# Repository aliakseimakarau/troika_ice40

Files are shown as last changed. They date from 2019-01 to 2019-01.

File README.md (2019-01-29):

This is an implementation of the Troika hashing algorithmus on ICE40 FPGAs.

The repository is intended to be used by developers who are considering using Troika in their hardware projects. The board-files are from a PoC which can be used as design example.

It's not a high-performance solution because it needs multiple clock-cycles per hash-round and the implementation is heavily restricted by logic resources and achievable speed of ICE40 FPGAs. But the FPGA is very cheap, the PCB can be done by any cheap chinese manufacturer and soldering is doable with a bit of practice. And it's a lot faster than doing hash calculations only in software if using e.g. auto-padding and/or multi-hash-loops. IOTA library functions can benefit much because 1. it works much with 243Trit vectors and 2. they often do multiple hashing loops (e.g. address generation, signing).

Support for this repository is limited because it's just a PoC and intended for experienced developers. (by the way, it's the same PCB as for the PoWChip PoC - for Troika the GSM/BT/GPS modul is not needed and software for it is not included in the repository).

Some features (FPGA):
- ICE40UP5K ($5 FPGA in QFN package)
- FPGA about 73% utilized
- running at 36MHz (uses internal 48MHz oscillator + PLL; no external oscillator required)
- Data-transfers via SPI
- It needs 55 clock cycles per hash
- It can do auto-padding for 243Trit input size (single Block; in IOTA used a lot)
- It can do multiple loops with auto-padding (this is interesting for e.g. IOTA where often a block has to be hashed multiple times; It reduces transfer-times significantly)
- It supports nested hashing by "push"ing" and "pop"ing the internal Troika state to and from a "Stack" (actually, it's an internal offset for RAM address but it acts like a stack).

PCB:
- ICE40UP5K FPGA
- STM32F302CCTx µC (default DFU Bootloader can be used)
- Pinheader for GSM/GPS/BT module (not used in this application)
- Some LEDs, Buttons
- SWD Debug header

Performance:
- 10k blocks (including SPI transfer times) in 11.6s
- 1k blocks with 27 hash-loops (including SPI transfer times and auto-padding) in 2.6s

This repository contains:
- Radiant project files for ICE40 FPGAs with VHDL source files
- Example Board-Design
- Eclipse project with code for STM32F302

Just a small note ... A synthesized ICE40 Bitstream is included in the STM32-code (bitstream.h)

License (MIT):
```
-- 2018 by Thomas Pototschnig <microengineer18@gmail.com,
-- http://microengineer.eu
-- discord: pmaxuw#8292
-- donations-address: 
--     LLEYMHRKXWSPMGCMZFPKKTHSEMYJTNAZXSAYZGQUEXLXEEWPXUNWBFDWESOJVLHQHXOPQEYXGIRBYTLRWHMJAOSHUY
-- 
-- Permission is hereby granted, free of charge, to any person obtaining
-- a copy of this software and associated documentation files (the
-- "Software"), to deal in the Software without restriction, including
-- without limitation the rights to use, copy, modify, merge, publish,
-- distribute, sublicense, and/or sell copies of the Software, and to
-- permit persons to whom the Software is furnished to do so, subject to
-- the following conditions:
-- 
-- The above copyright notice and this permission notice shall be
-- included in all copies or substantial portions of the Software.
-- 
-- THE SOFTWARE IS PROVIDED "AS IS", WITHOUT WARRANTY OF ANY KIND,
-- EXPRESS OR IMPLIED, INCLUDING BUT NOT LIMITED TO THE WARRANTIES OF
-- MERCHANTABILITY, FITNESS FOR A PARTICULAR PURPOSE AND
-- NONINFRINGEMENT. IN NO EVENT SHALL THE AUTHORS OR COPYRIGHT HOLDERS BE
-- LIABLE FOR ANY CLAIM, DAMAGES OR OTHER LIABILITY, WHETHER IN AN ACTION
-- OF CONTRACT, TORT OR OTHERWISE, ARISING FROM, OUT OF OR IN CONNECTION
-- WITH THE SOFTWARE OR THE USE OR OTHER DEALINGS IN THE SOFTWAR
```

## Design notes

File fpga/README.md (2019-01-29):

This is an implementation of the Troika hashing algorithmus on ICE40 FPGAs.

The repository is intended to be used by developers who are considering using Troika in their hardware projects. The board-files are from a PoC which can be used as design example.

It's not a high-performance solution because it needs multiple clock-cycles per hash-round and the implementation is heavily restricted by the architecture (and logic resources) of ICE40 FPGAs. But the FPGA is very cheap, the PCB can be done by any cheap chinese manufacturer and soldering is doable with a bit of practice. And it's a lot faster than doing hash calculations only in software if using e.g. auto-padding and/or multi-hash-loops. IOTA library functions can benefit much because 1. the work much with 243Trit vectors and 2. they often do multiple hashing loops (e.g. address generation, signing).

Some features:
- ICE40UP5K ($5 FPGA in QFN package)
- FPGA about 73% utilized
- running at 36MHz (uses internal 48MHz oscillator + PLL; no external oscillator required)
- Data-transfers via SPI
- It needs 55 clock cycles per hash
- It can do auto-padding for 243Trit input size (single Block; in IOTA used a lot)
- It can do multiple loops with auto-padding (this is interesting for e.g. IOTA where often a block has to be hashed multiple times; It reduces transfer-times significantly)
- It supports nested hashing by "push"ing" and "pop"ing the internal Troika state to and from a "Stack" (actually, it's an internal offset for RAM address but it acts like a stack).

Performance:
- 10k blocks (including SPI transfer times) in 11.6s
- 1k blocks with 27 hash-loops (including SPI transfer times and auto-padding) in 2.6s

This repository contains:
- Radiant project files for ICE40 FPGAs with VHDL source files
- Example Board-Design
- Eclipse project with code for STM32F302

Just a small note ... A synthesized ICE40 Bitstream is included in the STM32-code (bitstream.h)

If you like my work please consider donating:
LLEYMHRKXWSPMGCMZFPKKTHSEMYJTNAZXSAYZGQUEXLXEEWPXUNWBFDWESOJVLHQHXOPQEYXGIRBYTLRWHMJAOSHUY

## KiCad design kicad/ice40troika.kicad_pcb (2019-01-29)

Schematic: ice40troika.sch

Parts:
C1, C2, C10, C11, C32, C34, C35: 1µ; C_0603_1608Metric
C3, C36: 10µ; C_0603_1608Metric
C4, C5, C6, C7, C12, C13, C16, C19, C20, C24, C25, C26, C27, C31, C33: 100n; C_0603_1608Metric
C8, C9, C14, C15, C18: 10n; C_0603_1608Metric
C17, C28, C29, C30: 47µ; C_1210_3225Metric
C21: 4.7µ/X5R; C_1206_3216Metric
C22, C23: 47p; C_0603_1608Metric
D1: D; D_SOD-523
D2, D3: LED; LED_0603_1608Metric
JP1: Jumper_NC_Dual; SolderJumper-3_P1.3mm_Open_RoundedPad1.0x1.5mm
P1: 10104110-0001LF; MICROUSBB
P2: CONN_01X05; PinHeader_1x05_P1.27mm_Vertical
R1, R2, R4, R6, R7, R9, R12, R18, R19, R22: 10k; R_0603_1608Metric
R3: 100; R_0603_1608Metric
R5: 100k; R_0603_1608Metric
R8, R11, R13, R20: 22; R_0603_1608Metric
R10: 1k5; R_0603_1608Metric
R14, R21: 270; R_0603_1608Metric
R15: 1; R_1210_3225Metric
R16, R17: 33; R_0603_1608Metric
SW1, SW2, SW3: KMR2; SW_SPST_KMR2
U1: ice40up5k; ice40up-QFN-48
U3: USBLC6-2SC6; SOT-23-6
U4: STM32F302CCT6; LQFP-48_7x7mm_P0.5mm
U5: SIM808
U6: LP2985-3.3; SOT-23-5
U7: MIC5504-1.2YM5; SOT-23-5
X1: 8MHz; Oscillator_SMD_Abracon_ASE-4Pin_3.2x2.5mm

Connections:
+1V2: C2.1, C6.1, C9.1, C31.1, R3.2, R15.1, U1.5, U1.30
+3V3: C1.1, C4.2, C5.1, C8.1, C10.1, C11.1, C12.1, C13.1, C14.1, C15.1, C16.1, C24.1, C25.1, C26.1, C27.1, C34.1, C36.1, D1.2, R1.2, R2.2, R4.2, R6.2, R9.1, R10.2, R14.1, R21.1, SW2.1, SW3.1, U1.1, U1.22, U1.33, U4.9, U4.24, U4.36, U4.48, U6.5 (VOUT), U7.1 (VIN), U7.3 (EN), X1.4
/CDONE: R4.1, U1.7, U4.11
/CLK_OUT: R20.2, U1.35
/CRESET_B: R2.1, U1.8, U4.10
/D+: R10.1, R17.2, U3.1
/D-: R16.2, U3.3
/GSM_PWRKEY: U4.19, U5.K
/GSM_RXD: U4.12, U5.R
/GSM_SLEEP: U4.18, U5.S
/GSM_TXD: U4.13, U5.T
/LED_FOUND: D2.1, U1.2
/LED_OVERFLOW: U1.3
/LED_RUNNING: U1.4
/PLL_HOLD: R19.2, U1.34, U4.30
/POW_MISO: U1.46, U4.16
/POW_MOSI: U1.45, U4.17
/POW_RESET: U1.47
/POW_SCK: U1.44, U4.15
/POW_SS: U1.48, U4.14
/SPI_MISO: U1.14, U4.27
/SPI_MOSI: U1.17, U4.28
/SPI_SCK: R1.1, R11.2, U1.15
/SPI_SS: JP1.2, U1.16, U4.25
/SWCLK: P2.4, U4.37
/SWDIO: P2.3, U4.34
/SWITCH: R18.1, SW3.2
/USB_D+: C23.2, R17.1, U4.33
/USB_D-: C22.2, R16.1, U4.32
/spare1: U1.36, U4.22
/spare2: R13.2, U1.37
/spare3: U1.38, U4.20
ARM_NRST: C20.1, P2.2, R9.2, SW1.2, U4.7
GND: C1.2, C2.2, C3.2, C4.1, C5.2, C6.2, C7.2, C8.2, C9.2, C10.2, C11.2, C12.2, C13.2, C14.2, C15.2, C16.2, C17.2, C18.1, C19.1, C20.2, C21.1, C22.1, C23.1, C24.2, C25.2, C26.2, C27.2, C28.2, C29.2, C30.2, C31.2, C32.2, C33.1, C34.2, C35.2, C36.2, P1.5, P1.6, P2.5, R5.2, R7.1, R12.2, R18.2, R19.1, R22.2, SW1.1, U1.49, U3.2, U4.8, U4.23, U4.35, U4.47, U5.G, U6.2 (GND), U7.2 (GND), X1.2
unnamed: C3.1, C7.1, R3.1, U1.29
unnamed: C33.2, U6.4 (BP)
unnamed: C35.1, R15.2, U7.5 (VOUT)
unnamed: D1.1, U1.24
unnamed: D2.2, R14.2
unnamed: D3.1, U4.41
unnamed: D3.2, R21.2
unnamed: JP1.1, R6.1
unnamed: JP1.3, R7.2
unnamed: P1.2, U3.4
unnamed: P1.3, U3.6
unnamed: P1.4, R5.1
unnamed: R8.1, U4.5
unnamed: R8.2, X1.3
unnamed: R11.1, U4.26
unnamed: R12.1, SW2.2, U4.44
unnamed: R13.1, U4.21
unnamed: R20.1, U4.29
unnamed: R22.1, U4.46, X1.1
POWER_USB: C17.1, C18.2, C19.2, C21.2, C28.1, C29.1, C30.1, C32.1, P1.1, U3.5, U5.V, U6.1 (VIN), U6.3 (ON/~OFF~)

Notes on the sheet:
LO = Boot from flash

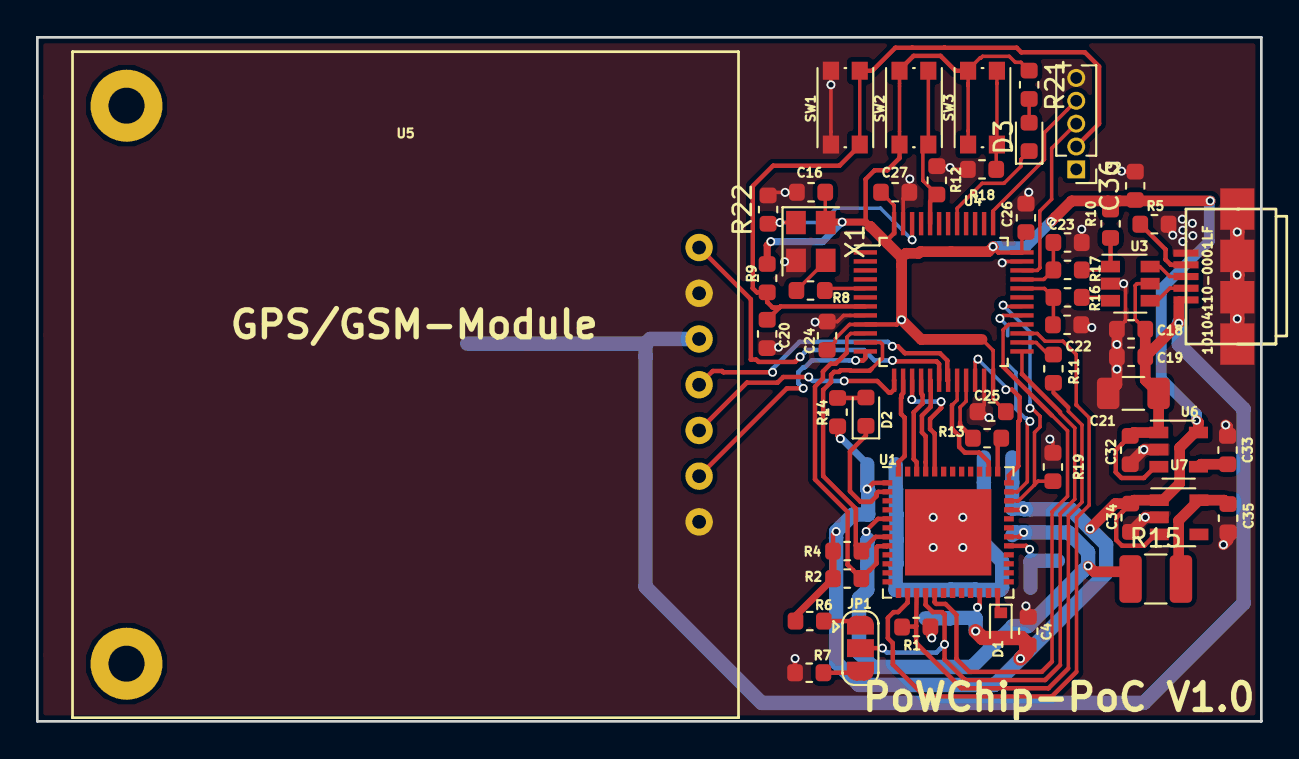
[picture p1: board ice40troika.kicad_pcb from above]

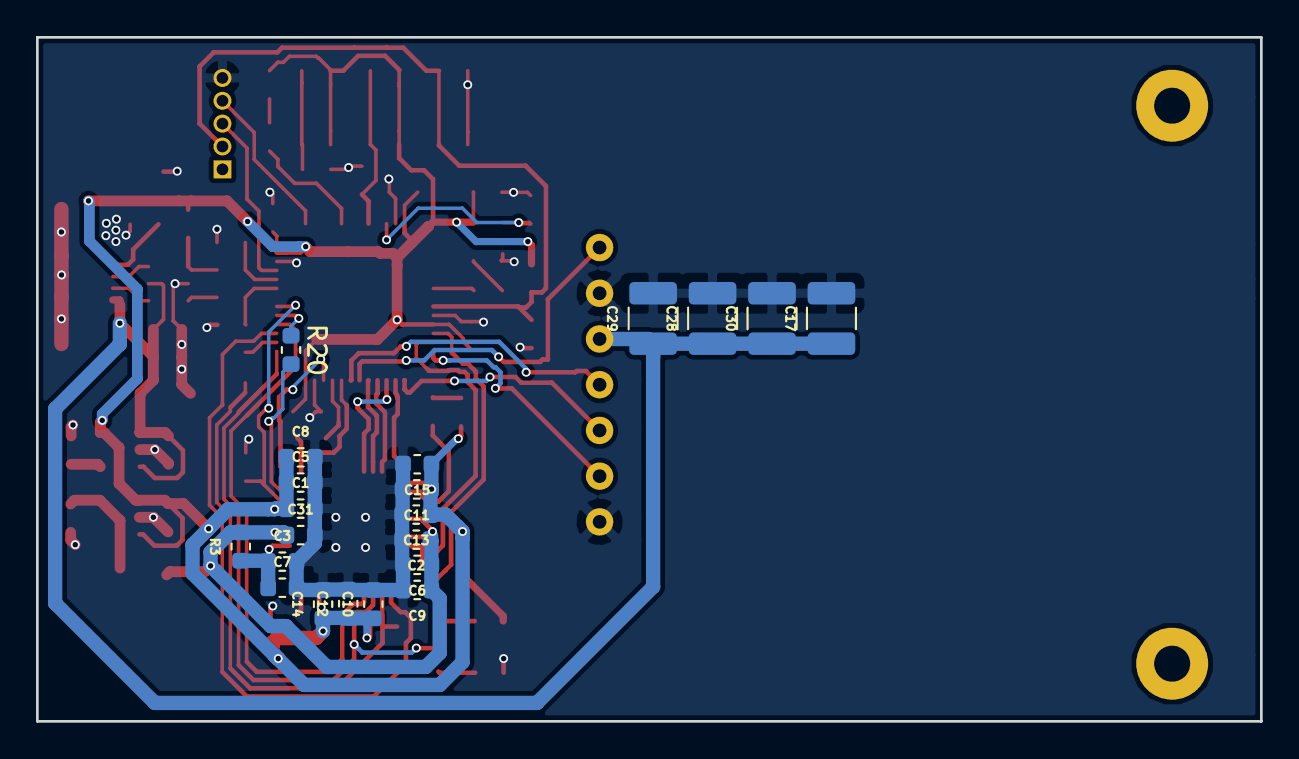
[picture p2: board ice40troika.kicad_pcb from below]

Board: 2 copper layers, 68.0 x 38.0 mm, 74 parts (21 on the bottom side), 51 nets.

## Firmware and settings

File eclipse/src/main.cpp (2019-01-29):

/*
-- Troika for ICE40-FPGA
--
-- 2018 by Thomas Pototschnig <microengineer18@gmail.com,
-- http://microengineer.eu
-- discord: pmaxuw#8292
-- donations-address:
--     LLEYMHRKXWSPMGCMZFPKKTHSEMYJTNAZXSAYZGQUEXLXEEWPXUNWBFDWESOJVLHQHXOPQEYXGIRBYTLRWHMJAOSHUY
--
-- Permission is hereby granted, free of charge, to any person obtaining
-- a copy of this software and associated documentation files (the
-- "Software"), to deal in the Software without restriction, including
-- without limitation the rights to use, copy, modify, merge, publish,
-- distribute, sublicense, and/or sell copies of the Software, and to
-- permit persons to whom the Software is furnished to do so, subject to
-- the following conditions:
--
-- The above copyright notice and this permission notice shall be
-- included in all copies or substantial portions of the Software.
--
-- THE SOFTWARE IS PROVIDED "AS IS", WITHOUT WARRANTY OF ANY KIND,
-- EXPRESS OR IMPLIED, INCLUDING BUT NOT LIMITED TO THE WARRANTIES OF
-- MERCHANTABILITY, FITNESS FOR A PARTICULAR PURPOSE AND
-- NONINFRINGEMENT. IN NO EVENT SHALL THE AUTHORS OR COPYRIGHT HOLDERS BE
-- LIABLE FOR ANY CLAIM, DAMAGES OR OTHER LIABILITY, WHETHER IN AN ACTION
-- OF CONTRACT, TORT OR OTHERWISE, ARISING FROM, OUT OF OR IN CONNECTION
-- WITH THE SOFTWARE OR THE USE OR OTHER DEALINGS IN THE SOFTWAR
*/


#include <stdio.h>
#include <stdlib.h>
#include <string.h>

#include "diag/Trace.h"

#include "gpio.h"

#include "Timer.h"
#include "fpga.h"
#include "hash.h"
//#include "converter.h"
#include "bitstream.h"


#define min(a,b) ((a<b)?a:b)

// Sample pragmas to cope with warnings. Please note the related line at
// the end of this function, used to pop the compiler diagnostics status.
#pragma GCC diagnostic push
#pragma GCC diagnostic ignored "-Wunused-parameter"
#pragma GCC diagnostic ignored "-Wmissing-declarations"
#pragma GCC diagnostic ignored "-Wreturn-type"

GPIOClass gpio;
FPGAClass fpga(&gpio);

extern volatile uint32_t systick;

extern "C" uint32_t getSysTick() {
	return systick;
}

extern "C" void delay(uint32_t d) {
	uint32_t start = systick;
	while (systick - start < d + 1)
		;
}

void troikaPrint(uint32_t* data) {
	char line[28]={0};
	char* p = line;
	trace_printf("---------------------------\n");
	for (int i=0;i<81;i++) {
		for (int j=0;j<9;j++) {
			*p++=((*data >> (2*j)) & 0x3)+48;
		}
		if ((i % 3)==2) {
			trace_printf("%s\n", line);
			p = line;
		}
		data++;
	}
}

int main(int argc, char* argv[]) {
	gpio.init();
	SystemInit();
	SystemCoreClockUpdate();

	Timer timer;
	timer.start();

	fpga.initSPI();

	fpga.startConfigure();
	fpga.uploadFPGA((uint8_t*) ice40troika_impl_1_bin, ice40troika_impl_1_bin_len);

	if (fpga.isConfigured()) {
		gpio.clr(GPIOClass::LED);
	}

	SystemCoreClockUpdate();

#ifdef DEBUG
	trace_printf("System clock: %u Hz\n", SystemCoreClock);
#endif

	uint8_t data[243]={0};
	data[0]=1;
	data[242]=2;
	uint32_t s = systick;
#if 0
	// single block
	for (int i=0;i<10000;i++) {
		fpga.troikaBlock(data, 1, true);	// 1 loop, auto-padding enabled
	}
#else
	// multiple hash loops
	for (int i=0;i<1000;i++)
		fpga.troikaHash243(data, 27);	// 27 loops, auto-padding enabled
#endif
	trace_printf("%d\n", systick-s);

	uint32_t hash[81]={0};
	fpga.troikaDigest(hash, 81);
	troikaPrint(hash);

	while (1) {
	}

	return 0;
}

#pragma GCC diagnostic pop

// ----------------------------------------------------------------------------

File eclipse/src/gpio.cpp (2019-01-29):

/*
-- Troika for ICE40-FPGA
--
-- 2018 by Thomas Pototschnig <microengineer18@gmail.com,
-- http://microengineer.eu
-- discord: pmaxuw#8292
-- donations-address:
--     LLEYMHRKXWSPMGCMZFPKKTHSEMYJTNAZXSAYZGQUEXLXEEWPXUNWBFDWESOJVLHQHXOPQEYXGIRBYTLRWHMJAOSHUY
--
-- Permission is hereby granted, free of charge, to any person obtaining
-- a copy of this software and associated documentation files (the
-- "Software"), to deal in the Software without restriction, including
-- without limitation the rights to use, copy, modify, merge, publish,
-- distribute, sublicense, and/or sell copies of the Software, and to
-- permit persons to whom the Software is furnished to do so, subject to
-- the following conditions:
--
-- The above copyright notice and this permission notice shall be
-- included in all copies or substantial portions of the Software.
--
-- THE SOFTWARE IS PROVIDED "AS IS", WITHOUT WARRANTY OF ANY KIND,
-- EXPRESS OR IMPLIED, INCLUDING BUT NOT LIMITED TO THE WARRANTIES OF
-- MERCHANTABILITY, FITNESS FOR A PARTICULAR PURPOSE AND
-- NONINFRINGEMENT. IN NO EVENT SHALL THE AUTHORS OR COPYRIGHT HOLDERS BE
-- LIABLE FOR ANY CLAIM, DAMAGES OR OTHER LIABILITY, WHETHER IN AN ACTION
-- OF CONTRACT, TORT OR OTHERWISE, ARISING FROM, OUT OF OR IN CONNECTION
-- WITH THE SOFTWARE OR THE USE OR OTHER DEALINGS IN THE SOFTWAR
*/

#include "gpio.h"
#include "stm32f30x_gpio.h"


#define GPIOA_LED		GPIO_Pin_0



//#define SPI_GPIO      GPIOB
#define GPIOA_MOSI  GPIO_Pin_7
#define GPIOA_MISO  GPIO_Pin_6
#define GPIOA_SCK  	GPIO_Pin_5
#define GPIOA_SS   	GPIO_Pin_3

#define GPIOB_nSTATUS	GPIO_Pin_4
#define GPIOB_DCK		GPIO_Pin_7
#define GPIOB_DATA0		GPIO_Pin_8
#define GPIOB_nCONFIG	GPIO_Pin_9
#define GPIOA_CONFDONE	GPIO_Pin_2
#define GPIOA_PIDETECT	GPIO_Pin_15

#define GPIOB_DISC		GPIO_Pin_2


#define GPIOB_GSM_SLEEP		GPIO_Pin_0
#define GPIOB_GSM_PWRKEY	GPIO_Pin_1

#define GPIOB_CONF_SS		GPIO_Pin_12
#define GPIOB_CONF_SCK		GPIO_Pin_13
#define GPIOB_CONF_MISO		GPIO_Pin_14
#define GPIOB_CONF_MOSI		GPIO_Pin_15

#define GPIOA_CRESET_B		GPIO_Pin_0
#define GPIOA_CDONE			GPIO_Pin_1
#define GPIOA_GSM_RXD		GPIO_Pin_2
#define GPIOA_GSM_TXD		GPIO_Pin_3
#define GPIOA_POW_SS		GPIO_Pin_4
#define GPIOA_POW_SCK		GPIO_Pin_5
#define GPIOA_POW_MISO		GPIO_Pin_6
#define GPIOA_POW_MOSI		GPIO_Pin_7
#define GPIOA_CLK_OUT		GPIO_Pin_8
#define GPIOA_PLL_HOLD		GPIO_Pin_9


/*
#define SPI_CONF_RCC	RCC_APB1Periph_SPI2
#define SPI_CONF		SPI2
#define SPI_GPIO_RCC	RCC_APB2Periph_GPIOB

#define SPI_POW_RCC		RCC_APB1Perip_SPI1
#define SPI_POW			SPI1
#define SPI_GPIO_RCC	RCC_APB2Periph_GPIOA
*/

void GPIOClass::set(GPIOPin* g) {
	GPIO_WriteBit(g->getGPIO(), g->getPinNr(), Bit_SET);
}

void GPIOClass::clr(GPIOPin* g) {
	GPIO_WriteBit(g->getGPIO(), g->getPinNr(), Bit_RESET);
}

void GPIOClass::set(PinsEnum e) {
	set(getGPIOPin(e));
}

void GPIOClass::clr(PinsEnum e) {
	clr(getGPIOPin(e));
}

GPIOPin* GPIOClass::getGPIOPin(PinsEnum e) {
	return Pins[e];
}

BitAction GPIOClass::read(GPIOPin* g) {
	return GPIO_ReadInputDataBit(g->getGPIO(), g->getPinNr()) ? Bit_SET : Bit_RESET;
}

BitAction GPIOClass::read(PinsEnum e) {
	return read(getGPIOPin(e));
}


GPIOClass::GPIOClass() {

//	Pins[PinsEnum::GSM_SLEEP] = new GPIOPinOut(GPIOB, GPIOB_GSM_SLEEP, Bit_SET);
//	Pins[PinsEnum::GSM_PWRKEY] = new GPIOPinOut(GPIOB, GPIOB_GSM_PWRKEY, Bit_SET);

	Pins[PinsEnum::CRESET_B] = new GPIOPinOut(GPIOA, GPIOA_CRESET_B, Bit_RESET);	// reset FPGA
	Pins[PinsEnum::CDONE] = new GPIOPinIn(GPIOA, GPIOA_CDONE, GPIO_PuPd_NOPULL);

	Pins[PinsEnum::CONF_SS] = new GPIOPinOut(GPIOB, GPIOB_CONF_SS, Bit_RESET);		// low = configure as spi slave
	Pins[PinsEnum::CONF_SCK] = new GPIOPinOut(GPIOB, GPIOB_CONF_SCK, Bit_RESET);
	Pins[PinsEnum::CONF_MOSI] = new GPIOPinOut(GPIOB, GPIOB_CONF_MOSI, Bit_RESET);
	Pins[PinsEnum::CONF_MISO] = new GPIOPinIn(GPIOB, GPIOB_CONF_MISO, GPIO_PuPd_NOPULL);

	Pins[PinsEnum::LED] = new GPIOPinOut(GPIOB, GPIOB_LED, Bit_SET);

	Pins[PinsEnum::HSE_EN] = new GPIOPinOut(GPIOB, GPIOB_HSE_EN, Bit_SET);

//	Pins[PinsEnum::GSM_TXD] = new GPIOPinIn(GPIOA, GPIOA_GSM_TXD, GPIO_PuPd_NOPULL);
//	Pins[PinsEnum::GSM_RXD] = new GPIOPinOut(GPIOA, GPIOA_GSM_RXD, Bit_SET);

	Pins[PinsEnum::POW_SS] = new GPIOPinOut(GPIOA, GPIOA_POW_SS, Bit_SET);
/*	Pins[PinsEnum::POW_SCK] = new GPIOPinAF(GPIOA, GPIOA_POW_SCK, Bit_RESET);
	Pins[PinsEnum::POW_MOSI] = new GPIOPinAF(GPIOA, GPIOA_POW_MOSI, Bit_RESET);
	Pins[PinsEnum::POW_MISO] = new GPIOPinAF(GPIOA, GPIOA_POW_MISO, GPIO_PuPd_NOPULL, Bit_SET);*/

	Pins[PinsEnum::PLL_HOLD] = new GPIOPinOut(GPIOA, GPIOA_PLL_HOLD, Bit_RESET);
//	Pins[PinsEnum::CLK_OUT] = new GPIOPinOut(GPIOA, GPIOA_CLK_OUT, Bit_RESET);
}
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

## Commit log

2019-01-29 changed readme; forgot to git add files
    [pow_pll1.cfg]
2019-01-29 eclipse project and kicad schematic added
    [ice40troika.kicad_pcb, ice40troika.sch, myboard.cfg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]
